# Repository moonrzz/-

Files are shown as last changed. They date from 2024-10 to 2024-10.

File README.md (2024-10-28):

# 寝室物联网智能开关详细设计说明书

## 1. 引言

### 1.1 设计目的
设计一个基于物联网的舵机单元，实现在寝室WIFI环境下，管理员可以使用微信小程序联网远程控制舵机对寝室顶灯开关进行控制。

### 1.2 背景
由于主创开发者总是在课余时间编写代码或设计项目结构，经常在其余舍友上床后开始洗漱，然而其记性较差，每次都忘记关灯。鉴于舍友有网页前端设计、硬件电路设计经验，遂策划发起本项目。

### 1.3 参考资料
- [阿里云物联网平台最完全的使用教程-CSDN@一条草鱼](http://t.csdnimg.cn/A1NuI)
- [物联网微信小程序接入阿里云物联网平台-CSDN@指针阿飞](http://t.csdnimg.cn/tyo0F)
- [使用微信小程序连接到 MQTT 云服务-ZHIHU@EMQ](https://zhuanlan.zhihu.com/p/406581345)
- [Arduino ESP8266控制SG90舵机输出PWM信号-CSDN@西米33](http://t.csdnimg.cn/ka6XH)

### 1.4 项目成员
- **郑皓文** - 硬件结构设计、硬件电路焊接、舵机端软件设计、云服务器端调试（光赛经验）
- **张建权** - 小程序WEB前端页面设计、云服务器接口对接（星辰工作室骨干、WEB前端开发经验）
- **刘畅** - 开发板引脚分配、硬件电路拓扑、PCB板设计绘制（启梦杯硬件设计经验）

## 2. 项目系统的软件结构

智能开关系统的软件执行逻辑

## 3. 项目详细设计说明暨设计流程

### 3.1 云服务器端配置
本项目云服务器端使用阿里云公司提供的免费物联网云平台。根据参考资料成功完成云服务器上的手机端、舵机端设备实例的创建，并利用阿里云物联网平台的在线调试功能，实现了两设备之间的云产品流转与消息转发。

物联网云服务器的配置

### 3.2 开发板验证与下位机程序设计
本项目利用Arduino IDE开发ESP8266开发板，利用开发板的WIFI模组与阿里云官方提供的MQTT云服务库实现了下位机与云服务器的通讯。

下位机开发板调试记录

### 3.3 硬件电路拓扑与PCB设计与打板
项目成员首先根据ESP8266开发板的IO口引出图以及软件程序的设计对开发板进行引脚分配，便于PCB布线。

主板硬件电路拓扑

### 3.4 微信小程序前端页面设计及服务器接口对接
本项目根据MQTT云服务官方提供的订阅模板实现与阿里云服务器的接口对接，使用 HTML/CSS/Javascript 语言对小程序页面进行视觉设计，并设计按键回调函数。

小程序端页面设计与接口对接

### 3.5 硬件结构设计
在本项目中，使用650mAH锂电池连接CD42电源模块+TYPE-C母座实现产品的升压与充放电、电量显示功能。

电源结构设计

## 4. 产品成品展示

产品成品展示图

---

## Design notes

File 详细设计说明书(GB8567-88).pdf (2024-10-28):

# 寝室物联网智能开关 详细设计说明书

# 1 引言

## 1.1 设计目的

设计一个基于物联网的舵机单元，实现在寝室 WIFI 环境下，管理员可以使用微信小程 序联网远程控制舵机对寝室顶灯开关进行控制。

## 1.2 背景

由于主创开发者总是在课余时间编写代码或设计项目结构，经常在其余舍友上床后开始 洗漱，然而其记性较差，每次都忘记关灯，鉴于舍友有网页前端设计、硬件电路设计经验， 遂策划发起本项目。

## 1.3 参考资料

[1]阿里云物联网平台最完全的使用教程-CSDN@一条草鱼 http://t.csdnimg.cn/A1NuI
[2] 【 物 联 网 】 微 信 小 程 序 接 入 阿 里 云 物 联 网 平 台 -CSDN@ 指 针 阿 飞

http://t.csdnimg.cn/tyo0F
[3] 使 用 微 信 小 程 序 连 接 到 | MQTT | 云 服 务 -ZHIHU@EMQ

https://zhuanlan.zhihu.com/p/406581345
[4]Arduino ESP8266 控制 SG90 舵机输出 PWM 信号 -CSDN@ 西米 33

http://t.csdnimg.cn/ka6XH

## 1.4 项目成员

[Ⅰ]郑皓文-硬件结构设计、硬件电路焊接、舵机端软件设计、云服务器端调试（光赛经验） [Ⅱ]张建权-小程序 WEB 前端页面设计、云服务器接口对接（星辰工作室骨干、WEB 前端 开发经验）
[Ⅲ]刘畅-开发板引脚分配、硬件电路拓扑、PCB 板设计绘制（启梦杯硬件设计经验） （详细设计说明部分中，除特殊标注外，均为成员[Ⅰ]完成）

# 2 项目系统的软件结构

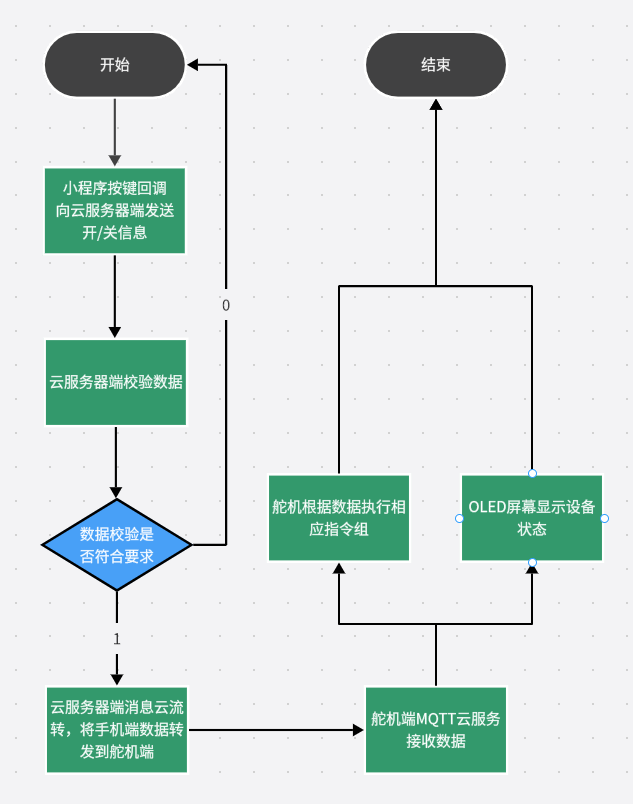
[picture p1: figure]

图（1） 智能开关系统的软件执行逻辑

# 3 项目详细设计说明暨设计流程

## 3.1 云服务器端配置

本项目云服务器端使用阿里云公司提供的免费物联网云平台，实名认证后仅需持续使用 便可获得免费使用期限。根据参考资料[1]的教程，成功完成云服务器上的手机端、舵机端 设备实例的创建，并且利用阿里云物联网平台的在线调试功能，实现了两设备之间的云产品 流转与消息转发。

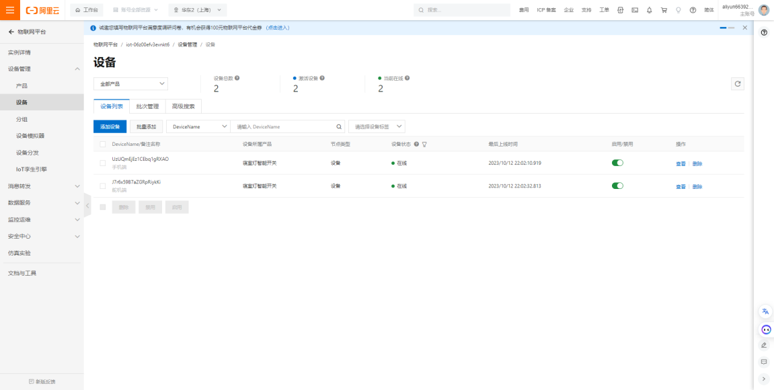
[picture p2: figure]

图（2） 物联网云服务器的配置

## 3.2 开发板验证与下位机程序设计

本项目利用 ARDUINO IDE 开发 ESP8266 开发板，利用开发板的 WIFI 模组与阿里云官 方提供的 MQTT 云服务库实现了下位机与云服务器的通讯，下位机能够成功接收上位服务 器发送的数据并将其存入变量。
随后将开发板连接 MG-90S 舵机与 0.96’OLED 屏幕，成功驱动后设计指令组，令其对 上述变量值的变化作出不同响应。

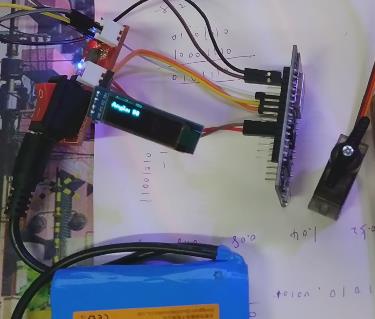
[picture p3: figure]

图（3） 下位机开发板调试记录
（图中从左至右，从上到下依次为电源模块、OLED 屏幕、物联网开发板、舵机、电池） 至此，本项目的最简系统设计完毕，随后将进行后续封装与一体化产品设计。

## 3.3 硬件电路拓扑与 PCB 设计与打板

（本部分由成员[Ⅲ]完成）
由于完全使用线材连接会使本产品略显杂乱且不便于外壳结构的设计，遂进行主板的设 计，将开发板、舵机、屏幕的接口统一到一块 PCB 电路板上，既能使设计美观又能方便后 续外壳结构的设计，使本项目产品化。

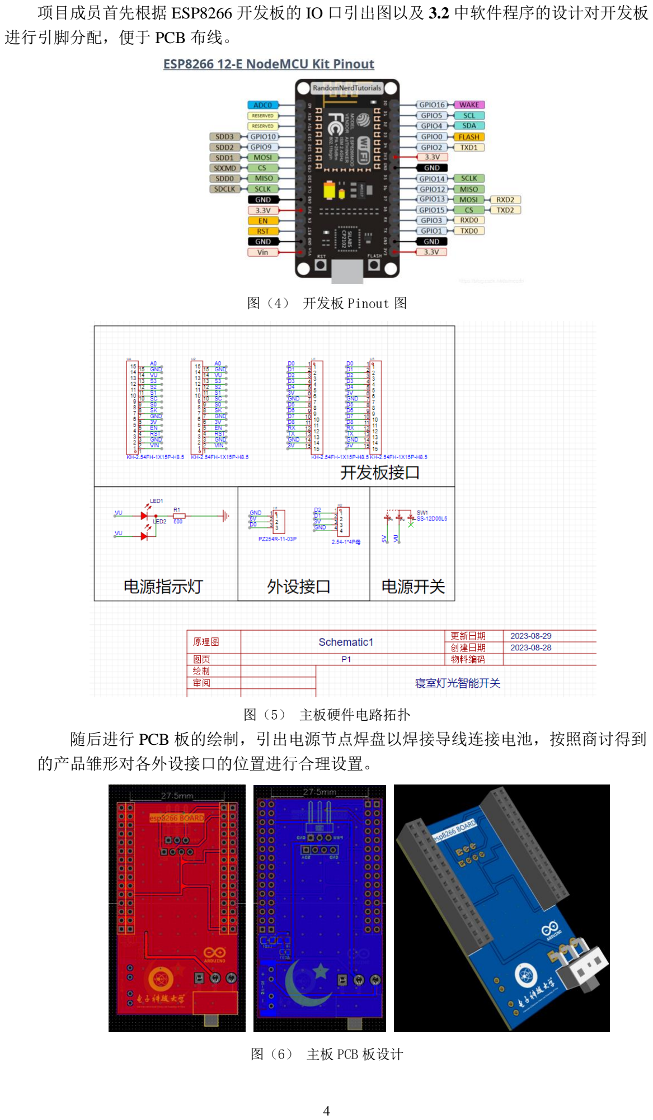
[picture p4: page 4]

项目成员首先根据 ESP8266 开发板的 IO 口引出图以及 3.2 中软件程序的设计对开发板 进行引脚分配，便于 PCB 布线。

图（4） 开发板 Pinout 图

图（5） 主板硬件电路拓扑
随后进行 PCB 板的绘制，引出电源节点焊盘以焊接导线连接电池，按照商讨得到 的产品雏形对各外设接口的位置进行合理设置。

图（6） 主板 PCB 板设计

## 3.4 微信小程序前端页面设计及服务器接口对接

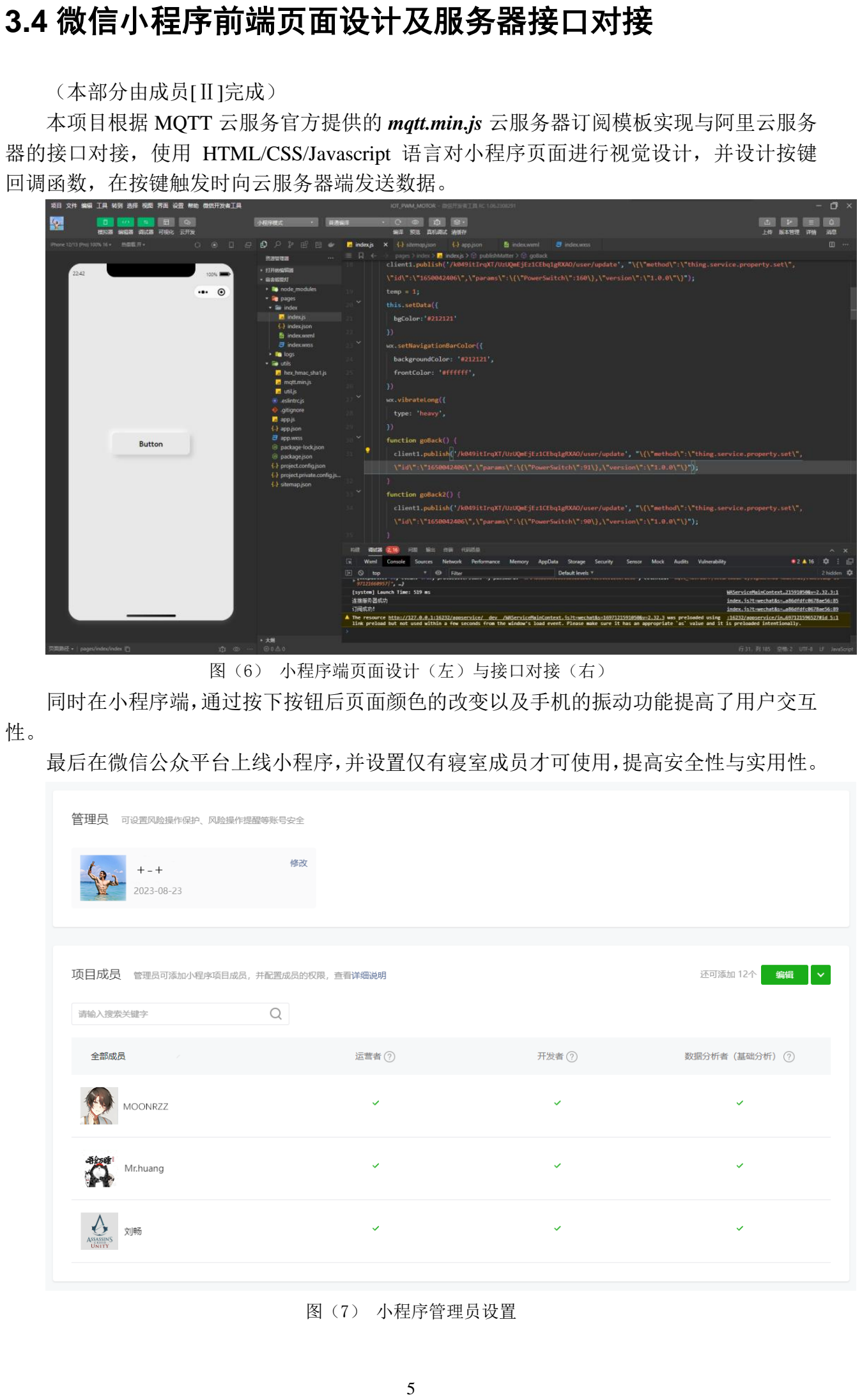
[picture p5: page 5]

（本部分由成员[Ⅱ]完成）
本项目根据 MQTT 云服务官方提供的 mqtt.min.js 云服务器订阅模板实现与阿里云服务 器的接口对接，使用 HTML/CSS/Javascript 语言对小程序页面进行视觉设计，并设计按键 回调函数，在按键触发时向云服务器端发送数据。

图（6） 小程序端页面设计（左）与接口对接（右）
同时在小程序端，通过按下按钮后页面颜色的改变以及手机的振动功能提高了用户交互 性。
最后在微信公众平台上线小程序，并设置仅有寝室成员才可使用，提高安全性与实用性。

图（7） 小程序管理员设置

## 3.5 硬件结构设计

在本项目中，使用 650mAH 锂电池连接 CD42 电源模块+TYPE-C 母座实现产品的升压 与充放电、电量显示功能。

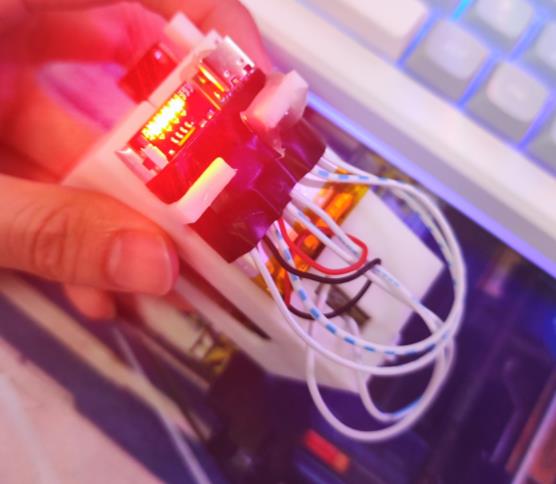
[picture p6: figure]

图（8） 电源结构设计（左起分别为电源模块、TYPE-C 母座） 在本项目中，为了方便产品的安装，对寝室顶灯开关进行精确尺寸测量并利用 Solidworks 建模软件完成舵机支架、主机外壳的设计。在舵机支架上预留出固定孔，在主机 外壳上预留出 WIFI 天线槽、舵机接线口、屏幕开槽、固定孔、电池仓。并与 3.3 中导出的 PCB 模型文件与官方提供的开发板、屏幕以及自行绘制的电源板、电池模型进行装配体设 计，完成产品系统整体的模型搭建。

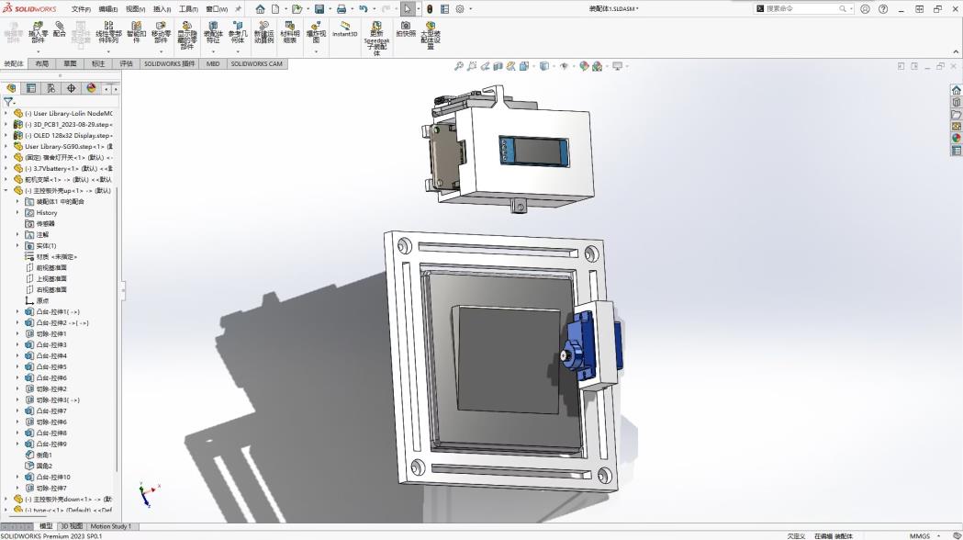
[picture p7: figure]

图（9） 产品系统模型搭建
但在实际运行中发现，先前低估了 WIFI 模组的功耗（110mA 待机电流），使用锂电池 至多仅可续航 3h,因此后续外接 10000mAH 的充电宝，在满电情况下，可满足 3~4 天的续航 要求。

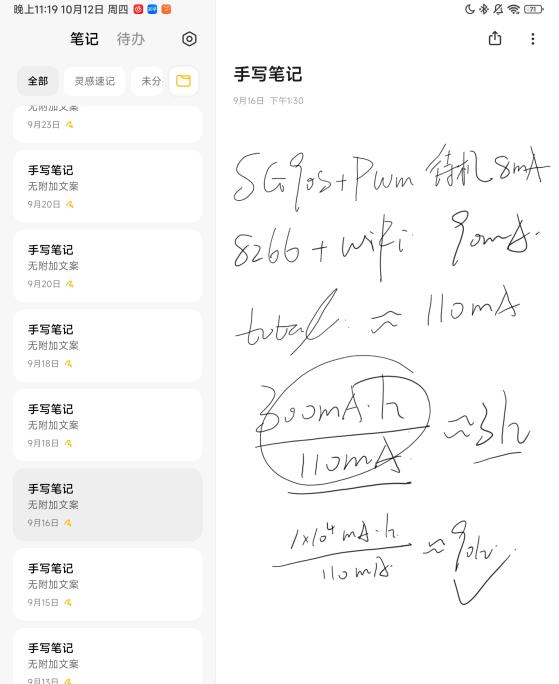
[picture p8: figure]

图（10） 电源功耗的研讨笔记 9.16

# 4 产品成品展示

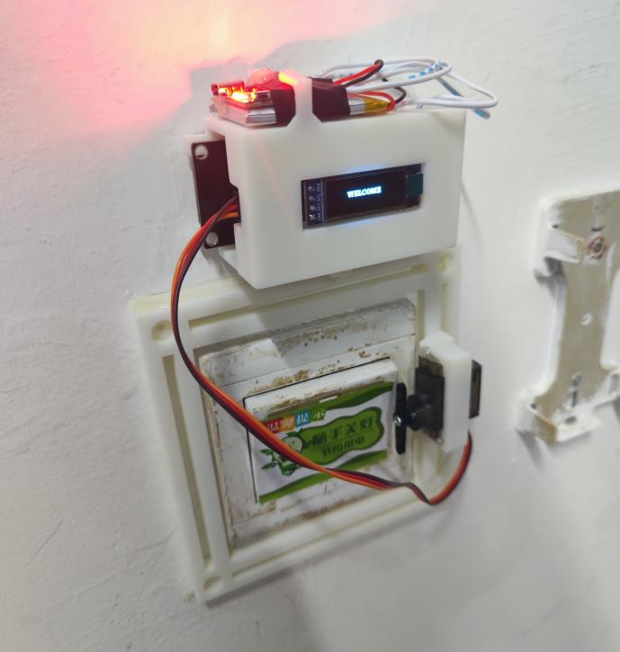
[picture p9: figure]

图（11） 产品成品展示图
此致

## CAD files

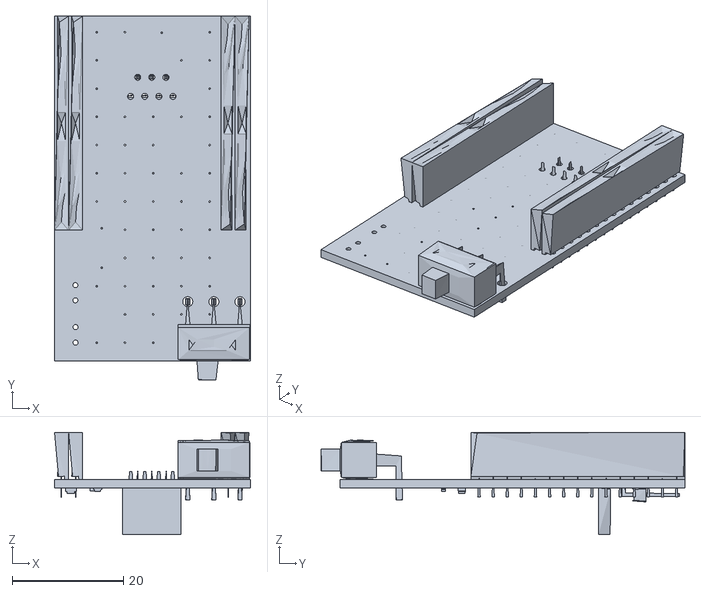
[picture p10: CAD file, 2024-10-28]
3D_PCB1_2024-10-08/3D_PCB1_2024-10-08.obj
35.3 x 65.5 x 18.4

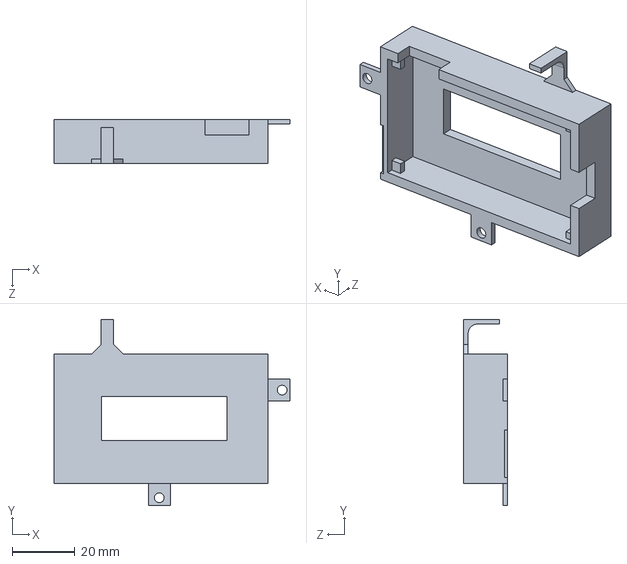
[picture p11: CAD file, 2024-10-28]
HARDWARE/主控板外壳up.SLDPRT
75.1 x 59.3 x 14.0 mm

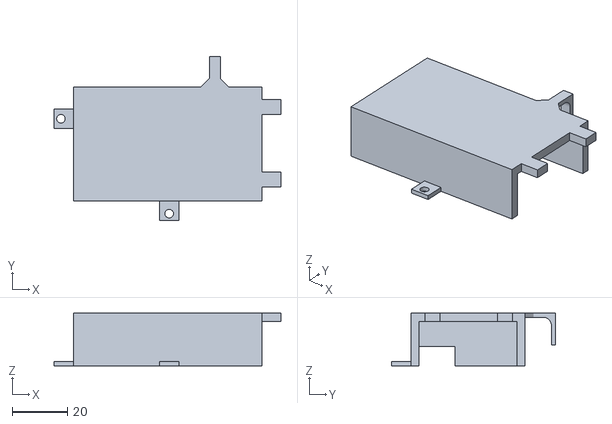
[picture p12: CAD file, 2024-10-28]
HARDWARE/打印件/主控板外壳down.STL
81.9 x 59.3 x 19.0

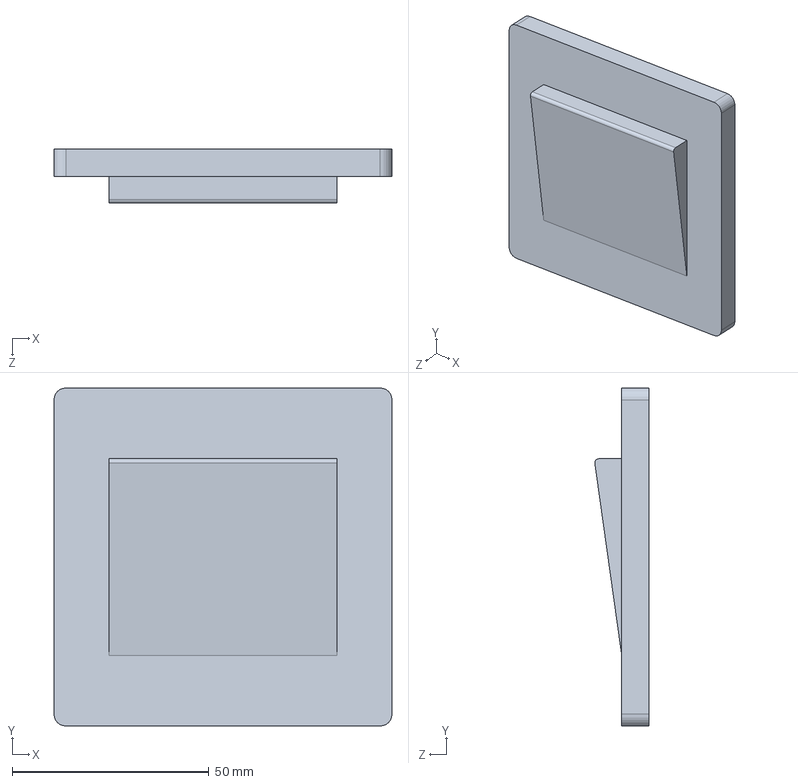
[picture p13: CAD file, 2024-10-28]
HARDWARE/宿舍灯开关.SLDPRT
86.0 x 86.0 x 13.8 mm

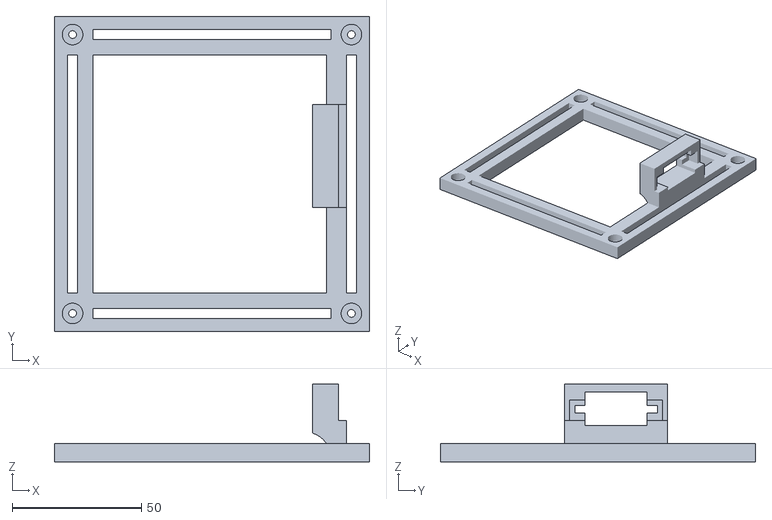
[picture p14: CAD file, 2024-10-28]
HARDWARE/打印件/server.STL
122.0 x 122.0 x 30.1

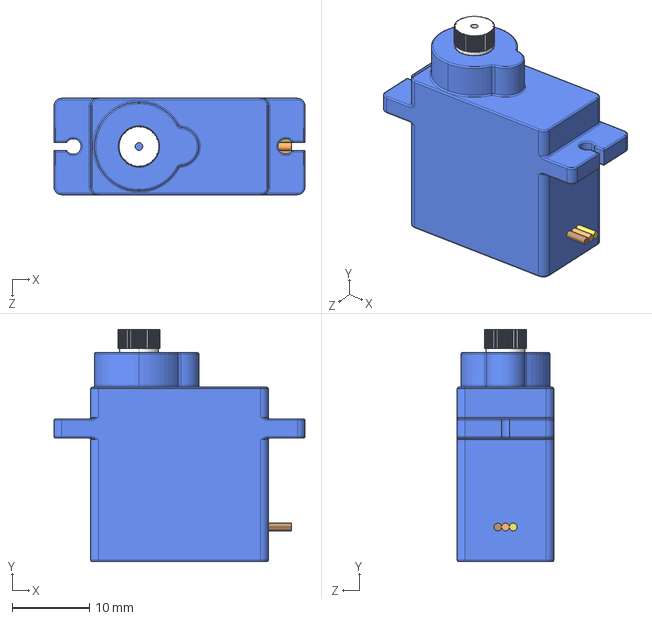
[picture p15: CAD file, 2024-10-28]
HARDWARE/User Library-SG90.step
32.5 x 30.1 x 12.5 mm

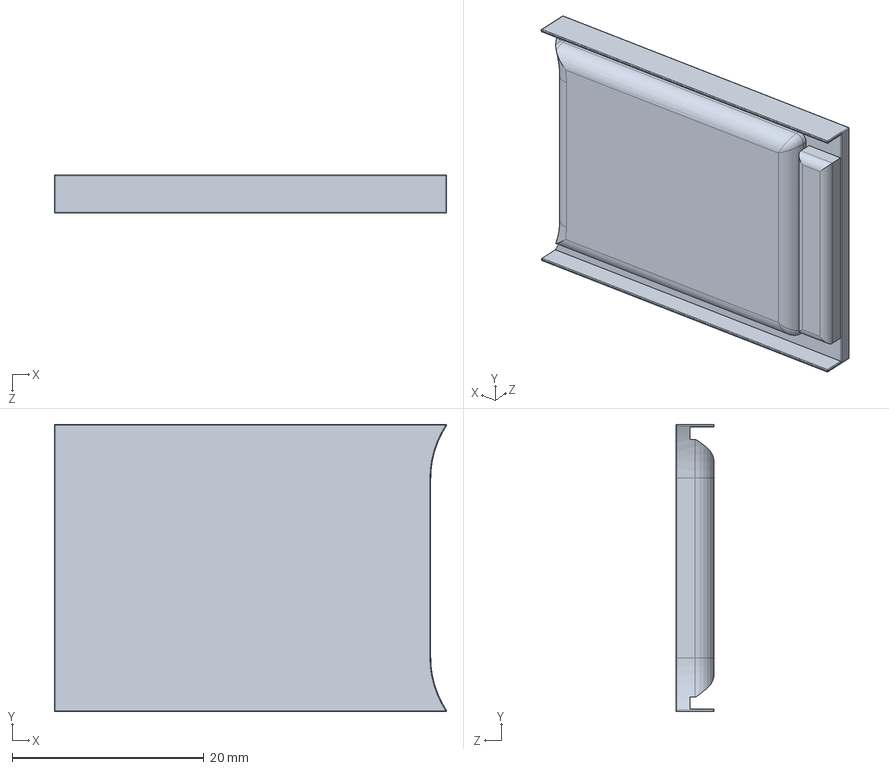
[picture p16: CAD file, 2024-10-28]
HARDWARE/3.7Vbattery.SLDPRT
40.9 x 30.0 x 4.00 mm

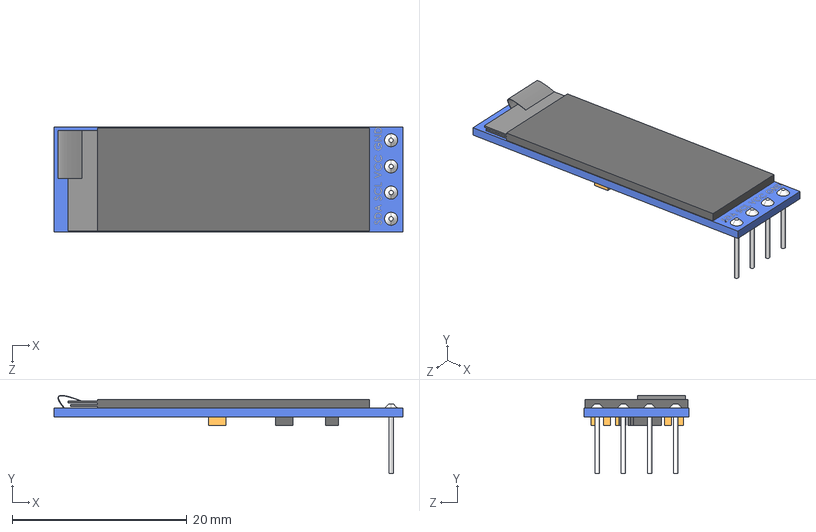
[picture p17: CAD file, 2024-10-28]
HARDWARE/User Library-OLED 32x 128.step
40.0 x 8.96 x 12.0 mm

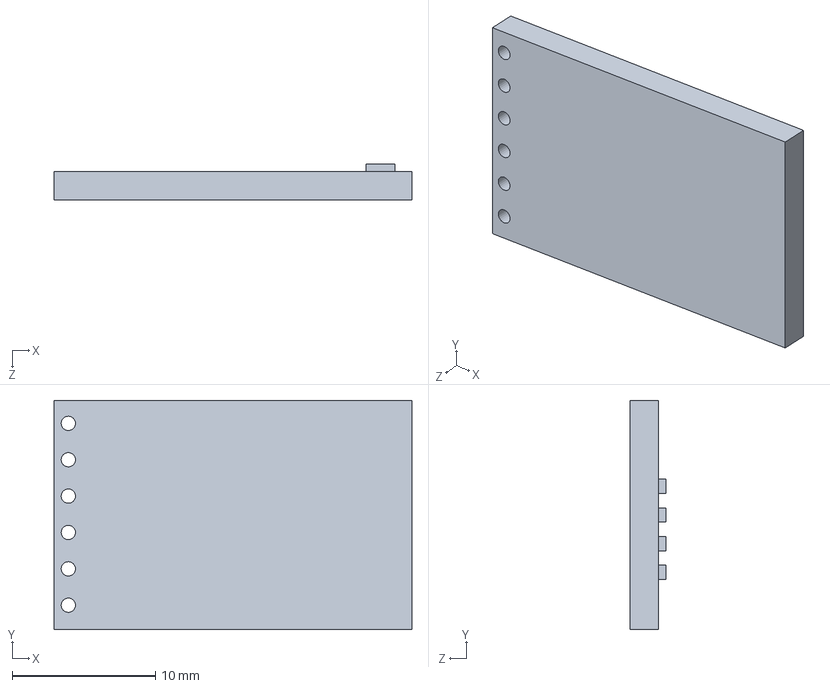
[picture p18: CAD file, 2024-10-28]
HARDWARE/电源模块.SLDPRT
25.0 x 16.0 x 2.50 mm

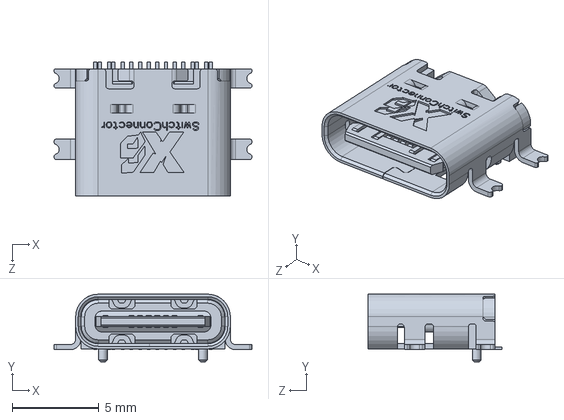
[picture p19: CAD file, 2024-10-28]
HARDWARE/type-c.SLDPRT
11.4 x 3.91 x 7.75 mm

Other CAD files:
HARDWARE/打印件/主控板外壳up.STL
HARDWARE/舵机支架.SLDPRT
HARDWARE/主控板外壳down.SLDPRT

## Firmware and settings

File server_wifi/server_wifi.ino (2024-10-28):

// #include <MUIU8g2.h>
#include <U8g2lib.h>
// #include <U8x8lib.h>
#include <Arduino.h>
#include <stdio.h>
#ifdef U8X8_HAVE_HW_SPI
#include <SPI.h>
#endif
#ifdef U8X8_HAVE_HW_I2C
#include <Wire.h>
#endif
U8G2_SSD1306_128X32_UNIVISION_F_SW_I2C u8g2(U8G2_R0, /* clock=*/ SCL, /* data=*/ SDA, /* reset=*/ U8X8_PIN_NONE);   // Adafruit Feather ESP8266/32u4 Boards + FeatherWing OLED
// 引入 wifi 模块，并实例化，不同的芯片这里的依赖可能不同
#include <ESP8266WiFi.h>
static WiFiClient espClient;

// 引入阿里云 IoT SDK
#include <AliyunIoTSDK.h>

// 设置产品和设备的信息，从阿里云设备信息里查看
#define PRODUCT_KEY "k049itIrqXT"
#define DEVICE_NAME "J7r6x59B7aZGRpRiykKi"
#define DEVICE_SECRET "4dc96b97d961de9fb45ed8c7ccade09e"
#define REGION_ID "cn-shanghai"

// 设置 wifi 信息
#define WIFI_SSID "wantopen"
#define WIFI_PASSWD "zhenghaoyue201532"
int pwmPin = 16;
int PowerSwitch = 90;
char str1[20];
char str2[20];
char str3[20];
char str4[20];
void setup()
{
  u8g2.begin();
  sprintf(str1,"LIGHT ON!");
  sprintf(str2,"LIGHT OFF!");
  sprintf(str3,"WELCOME");
  sprintf(str4,"INITIALIZING...");
  // u8g2.drawStr(20,20,str4);
  // pinMode(pwmPin, OUTPUT);
  analogWriteFreq(50);
  analogWriteRange(200);
  Serial.begin(115200);

  // 初始化 wifi
  wifiInit(WIFI_SSID, WIFI_PASSWD);

  // 初始化 iot，需传入 wifi 的 client，和设备产品信息
  AliyunIoTSDK::begin(espClient, PRODUCT_KEY, DEVICE_NAME, DEVICE_SECRET, REGION_ID);

  // 绑定一个设备属性回调，当远程修改此属性，会触发 powerCallback
  // PowerSwitch 是在设备产品中定义的物联网模型的 id
  AliyunIoTSDK::bindData("PowerSwitch", powerCallback);

  // 发送一个数据到云平台，LightLuminance 是在设备产品中定义的物联网模型的 id
  AliyunIoTSDK::send("LightLuminance", 100);
}
void pwm_server(int timePwm)
{
  // int i, a;
  //  for (a = 0; a < 100; a++)
  //  {
  //    for (i = 0; i < 5 * (50 + timePwm); i++)
  //    {
  //      digitalWrite(pwmPin, HIGH);
  //    }
  //    for (i = 0; i < 5 * 2000; i++)
  //    {
  //      digitalWrite(pwmPin, LOW);
  //    }
  //  }
  analogWrite(pwmPin, (int)(5 + (((float)timePwm / 180) * 20)));
}
void loop()
{
  AliyunIoTSDK::loop();
  u8g2.clearBuffer();					// clear the internal memory
  u8g2.setFont(u8g2_font_ncenB08_tr);	// choose a suitable font
  // sprintf(str1,"Angle:%4d",PowerSwitch);

  if(PowerSwitch < 90){
    u8g2.drawStr(30,20,str1);	// write something to the internal memory
  }
  else if(PowerSwitch == 90){
    u8g2.drawStr(30,20,str3);	// write something to the internal memory
  }
  else{
    u8g2.drawStr(30,20,str2);	// write something to the internal memory
  }
 
  u8g2.sendBuffer();
}

// 初始化 wifi 连接
void wifiInit(const char *ssid, const char *passphrase)
{
  WiFi.mode(WIFI_STA);
  WiFi.begin(ssid, passphrase);
  while (WiFi.status() != WL_CONNECTED)
  {
    delay(1000);
    Serial.println("WiFi not Connect");
  }
  Serial.println("Connected to AP");
}

// 电源属性修改的回调函数
void powerCallback(JsonVariant p)
{
  PowerSwitch = p["PowerSwitch"];
  pwm_server(PowerSwitch);
  
  
  // if (PowerSwitch == 1) {
  //   Serial.println("111111111");
  //   // 启动设备
  // }

  // Serial.println("111111111");
}
